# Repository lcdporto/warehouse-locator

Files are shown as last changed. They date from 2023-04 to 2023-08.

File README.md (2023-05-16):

# Warehouse Locator - An LED based stock search helper
Identifying a specific stock items inside a dense environment, such as a warehouse, is difficult so we developed a LED strip based system that lights up around the stock item requested.

This system is connected via WiFi to a MQTT broker and is able to receive commands to light up any given set of LEDs.

## Set up the server
The server is simply a MQTT broker. To setup the server you need to install [Docker](https://docs.docker.com/get-docker/) and [Docker Compose](https://docs.docker.com/compose/install/).

1. Because this will be a publicly accessible MQT broker,before you run the server, you need to define its access credentials. For that create a file on ```server/mosquitto/mosquitto.passwd``` with your user and password separated by a colon, here is an example:
```
lcdporto:very-strong-password
```
2. Then you are ready to start the server:

```
docker-compose up -d
```
3. Before you can use it you need to encrypt the password file:
```
docker exec -it mosquitto mosquitto_passwd -U /mosquitto/config/mosquitto.passwd
```
4. Then restart your server with:
```
docker-compose restart mosquitto
```
Now your server is up and running!

## Prepare your device

The hardware is composed of a ESP32 and LED strips. The hardware connections are simple:
| ESP32  | LED strip |
| --- | --- |
| GPIO15 | DATA |
| GPIO16 | DATA |
| GPIO19 | DATA |
| GPIO22 | DATA |
| GPIO21 | DATA |
| GPIO25 | DATA |

You can change this pin assignment as well as add more LED strips on the firmware. Your limitation is the RAM usage and the pin count of your board.

1. First you need to setup your computer to build the firmware with one of the two methods:
   - At the time of this writing the recommended method is to use [VS Code](https://code.visualstudio.com/) and the [official PlatformIO extension](https://marketplace.visualstudio.com/items?itemName=platformio.platformio-ide) which is a procedure that works on Windows, macOS and Linux foloowing the [the official documentation.](https://platformio.org/platformio-ide).\
   - You can also use a CLI approach that is available on all major platforms as well which have Python installed (follow [this guide](https://wiki.python.org/moin/BeginnersGuide/Download)) and then on the ```firmware``` folder run the following lines on the terminal of your operative system:
    ```
    pip install --user platformio
    pio run --target upload
    ```
    **Note:** you may need to reboot your system between the two commands for the *pio* executable to be available.

2. Next, you need to configure your device's WiFi network and MQTT broker details. To do that, power up your device and search for a WiFi network named after this project "warehouse-locator-\<ID\>" (note down the ID, or check later with this). Connect to it and you should be promted to login to the network on a captive portal. There is where you find a form to fill in your WiFi credentials and MQTT server details. If your device fails to connect to the network the configuration WiFi network will show up again after a few seconds.\
Alternatively, you can upload a file containing the MQTT server details (```firmware/data/config.json```) to the ESP32 filesystem following the [this guide](https://randomnerdtutorials.com/esp32-vs-code-platformio-spiffs/). Keep in mind that you still need to follow the captive portal procedure to enter your WiFi credentials.

Now your device is connected to the internet and able to receive messages from your broker that change the state of the LED strips you have hooked up.

## Discover connected devices

To discover connected devices and check their ID, the topic ```warehouse-locator/+``` can be subscribed and devices will periodically publish on that topic to announce themselves and you can check their ID on the topic name they use. Notice that the subscription topic suggested has the "+" wildcard, this means you'll subscribe to all devices announce topic.

An example on how you can listen to these messages is [here](.examples/../examples/discover_devices.py).

## Send commands

The device can be controlled by sending a MQTT message to the broker identifying the device, led-strip and led index and two modes are supported:

### Single LED control
**Topic:** `warehouse-locator/<deviceId>/<strip-id>/<led-id>`\
**Payload:**
```json
{
  "color": {
    "r": 0,
    "g": 255,
    "b": 0
  },
  "timeout": 5
}
```

### Multiple LED control
**Topic:** `warehouse-locator/<deviceId>/multiple`\
**Payload:**
```json
{
  "strip": 3,
  "from": 1,
  "to": 4,
  "color": {
    "r": 255,
    "g": 255,
    "b": 255
  },
  "timeout": 5
}
```
**Note:** For maintenance purposes the LEDs can be blinked sequentially if the payload is not a JSON object and just set to ```all```

Examples for both modes can be found at the [examples](./examples) folder.

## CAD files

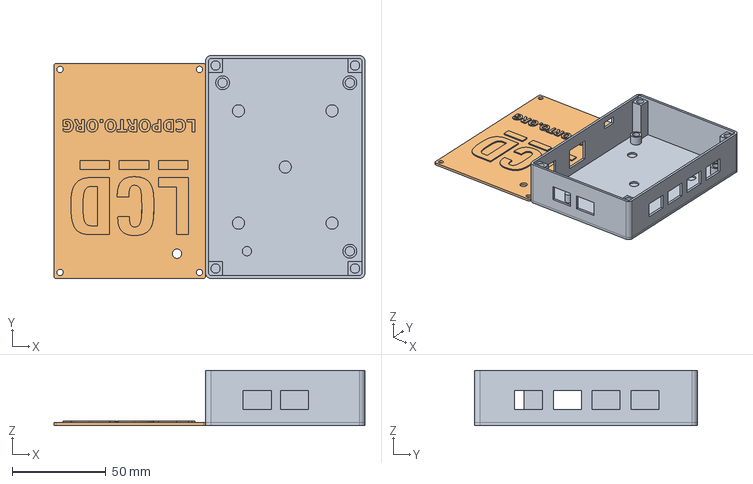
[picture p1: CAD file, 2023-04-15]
cad/warehouse-locator.FCStd
166.2 x 119.2 x 29.6 mm
case
lid

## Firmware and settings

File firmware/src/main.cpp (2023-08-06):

#include <ArduinoJson.h>
#include <EthernetENC.h>
#include <FastLED.h>
#define MQTT_MAX_PACKET_SIZE 2048
#include <PubSubClient.h>
#include <SPIFFS.h>
#include <WiFi.h>

#define LED_STRIP_1_PIN 2
#define LED_STRIP_2_PIN 4
#define LED_STRIP_3_PIN 16
#define LED_STRIP_4_PIN 17
#define LED_STRIP_5_PIN 21
#define LED_STRIP_6_PIN 22

#define NUM_LEDS 144 * 5
#define NUM_STRIPS 6

#define CONFIG_FILE_PATH "/config.json"
#define ID_FILE_PATH "/device-id.txt"

#define MQTT_TOPIC_PREFIX "warehouse-locator/"

#define MQTT_ANNOUNCE_PERIOD 30 // in seconds

#define LED_OFF_PAYLOAD "{\"color\":{\"r\": 0,\"g\": 0,\"b\":0}}"

#define MQTT_SERVER "test.mosquitto.org"
#define MQTT_PORT 1883
#define MQTT_USER "mqtt_user"
#define MQTT_PASS "mqtt_password"

char device_id[11] = "";

static CRGB led_strips[NUM_STRIPS][NUM_LEDS];

EthernetClient ethernet_client;
PubSubClient mqtt(ethernet_client);

static bool test_running = false;

char connection_state[64] = "";

typedef struct {
  uint8_t strip;
  uint16_t led[128];
  uint8_t n_leds;
  uint8_t r = 255;
  uint8_t g = 255;
  uint8_t b = 255;
  uint16_t timeout = 5;
} led_ctrl;

void control_LEDs(void *led_arg) {
  led_ctrl led;
  memcpy(&led, led_arg, sizeof(led_ctrl));

  for (uint8_t i = 0; i < led.n_leds; i++) {
    led_strips[led.strip][led.led[i]] = CRGB(led.r, led.g, led.b);
  }
  FastLED.show();

  vTaskDelay((led.timeout * 1000) / portTICK_PERIOD_MS);

  for (uint8_t i = 0; i < led.n_leds; i++) {
    led_strips[led.strip][led.led[i]] = CRGB(0, 0, 0);
  }
  FastLED.show();

  vTaskDelete(NULL);
}

/**
 * @brief Turns the LEDs of all LED strips sequentially in a fading sequence
 *
 * @param group_size number of LEDs to be lit at each time
 */
void LED_init_sequence(uint16_t group_size = 3) {
  test_running = true;
  for (uint16_t j = 0; j < NUM_LEDS; j++) {
    for (uint8_t i = 0; i < NUM_STRIPS; i++) {
      led_strips[i][j] = CRGB(255, 255, 255);
    }
    if (j - group_size >= 0) {
      for (uint8_t i = 0; i < NUM_STRIPS; i++) {
        led_strips[i][j - group_size] = CRGB(0, 0, 0);
      }
    }
    FastLED.show();
    log_d("Lighting up LED # %d", j);
  }
  test_running = false;
}

void mqtt_receive(char *topic, byte *payload, unsigned int length) {
  log_d("Message arrived [%s]: %s", topic, strndup((char *)payload, length));

  // skip prefix, device ID and forward slash
  topic += strlen(MQTT_TOPIC_PREFIX) + 10 + 1;

  log_d("Trimmed topic to %s", topic);

  char *token = strtok(topic, "/");
  if (strcmp(token, "multiple") == 0) {

    DynamicJsonDocument doc(2048);
    if (deserializeJson(doc, (char *)payload)) {
      log_e("Received invalid JSON");
      return;
    }
    log_d("Deserialized JSON successfully");
    log_d("Doc has size: %d", doc.size());

    uint16_t timeout;
    if (doc.containsKey("timeout")) {
      timeout = doc["timeout"];
    } else {
      timeout = 5;
    }

    log_d("Received command to control %d LEDs", doc["leds"].size());

    led_ctrl led_c;
    led_c.strip = doc["strip"];
    uint16_t from_led = doc["from"].as<uint16_t>();
    uint16_t to_led = doc["to"].as<uint16_t>();
    uint16_t nleds = to_led - from_led + 1;
    nleds = nleds > 128 ? 128 : nleds;
    for (uint8_t i = 0; i < nleds; i++) {
      led_c.led[i] = from_led + i;
    }
    led_c.n_leds = nleds;
    led_c.r = doc["color"]["r"];
    led_c.g = doc["color"]["g"];
    led_c.b = doc["color"]["b"];
    led_c.timeout = timeout;

    xTaskCreate(control_LEDs, "control_LEDs", 4096, &led_c, 1, NULL);
  } else if (strcmp(token, "test") == 0) {
    LED_init_sequence();
  } else {
    uint8_t strip_n;
    uint16_t led_n;

    strip_n = atoi(token);
    led_n = atoi(strtok(NULL, "/"));

    log_d("Addressed strip %u and led %u", strip_n, led_n);

    DynamicJsonDocument doc(128);
    if (deserializeJson(doc, (char *)payload)) {
      log_e("Received invalid JSON");
      return;
    }
    log_d("Deserialized JSON successfully");
    log_d("Doc has size: %d", doc.size());

    uint16_t timeout;
    if (doc.containsKey("timeout")) {
      timeout = doc["timeout"];
    } else {
      timeout = 5;
    }

    led_ctrl led_c;
    led_c.strip = strip_n;
    led_c.led[0] = led_n;
    led_c.n_leds = 1;
    led_c.r = doc["color"]["r"];
    led_c.g = doc["color"]["g"];
    led_c.b = doc["color"]["b"];
    led_c.timeout = timeout;

    xTaskCreate(control_LEDs, "control_LEDs", 4096, &led_c, 1, NULL);
  }
}

bool mqtt_connect() {
  if (mqtt.connected())
    return true;

  bool status = mqtt.connect(device_id, MQTT_USER, MQTT_PASS);

  if (status == false) {
    return false;
  }
  char topic[64];
  sprintf(topic, "%s%s/+/+", MQTT_TOPIC_PREFIX, device_id);
  mqtt.subscribe(topic, 1);
  log_v("Subscribed to topic: %s", topic);

  sprintf(topic, "%s%s/test", MQTT_TOPIC_PREFIX, device_id);
  mqtt.subscribe(topic);
  log_v("Subscribed to topic: %s", topic);

  sprintf(topic, "%s%s/multiple", MQTT_TOPIC_PREFIX, device_id);
  mqtt.subscribe(topic, 1);
  log_v("Subscribed to topic: %s", topic);

  log_i("Connected to MQTT server: %s:%d", MQTT_SERVER, MQTT_PORT);

  return mqtt.connected();
}

void mqtt_announce(void *) {
  while (1) {
    if (mqtt_connect()) {
      char topic[64];
      sprintf(topic, "%s%s", MQTT_TOPIC_PREFIX, device_id);
      mqtt.publish(topic, connection_state);
    }
    vTaskDelay(MQTT_ANNOUNCE_PERIOD * 1000 / portTICK_PERIOD_MS);
  }
}

void setup() {
  FastLED.addLeds<WS2812, LED_STRIP_1_PIN, GRB>(led_strips[0], NUM_LEDS);
  FastLED.addLeds<WS2812, LED_STRIP_2_PIN, GRB>(led_strips[1], NUM_LEDS);
  FastLED.addLeds<WS2812, LED_STRIP_3_PIN, GRB>(led_strips[2], NUM_LEDS);
  FastLED.addLeds<WS2812, LED_STRIP_4_PIN, GRB>(led_strips[3], NUM_LEDS);
  FastLED.addLeds<WS2812, LED_STRIP_5_PIN, GRB>(led_strips[4], NUM_LEDS);
  FastLED.addLeds<WS2812, LED_STRIP_6_PIN, GRB>(led_strips[5], NUM_LEDS);

  for (uint8_t i = 0; i < NUM_STRIPS; i++) {
    for (uint16_t j = 0; j < NUM_LEDS; j++) {
      led_strips[i][j] = CRGB(0, 0, 0);
    }
  }
  for (uint8_t i = 0; i < NUM_STRIPS; i++) {
    led_strips[i][0] = CRGB(64, 0, 0);
  }
  FastLED.show();

  SPIFFS.begin(true);
  if (SPIFFS.exists(ID_FILE_PATH)) {
    fs::File device_id_file = SPIFFS.open(ID_FILE_PATH, "r");
    device_id_file.readBytes(device_id, 11);
    device_id_file.close();
  } else {
    fs::File device_id_file = SPIFFS.open(ID_FILE_PATH, "w");
    sprintf(device_id, "%010u", esp_random());
    device_id_file.print(device_id);
    device_id_file.close();
  }

  log_i("Device ID: %s", device_id);

  Ethernet.init(5);
  uint8_t mac[6];
  WiFi.macAddress(mac);
  Ethernet.begin(mac);

  if (Ethernet.linkStatus() == LinkON) {
    sprintf(connection_state, "Ethernet: %s",
            Ethernet.localIP().toString().c_str());
  } else {
    delay(5000);
    ESP.restart();
  }
  log_i("%s", connection_state);
  if (strcmp(Ethernet.localIP().toString().c_str(), "0.0.0.0") == 0) {
    delay(5000);
    ESP.restart();
  }
  log_i("%s", connection_state);

  for (uint16_t i = 0; i < NUM_STRIPS; i++) {
    led_strips[i][0] = CRGB(0, 64, 0);
  }
  FastLED.show();
  delay(5000);
  for (uint16_t i = 0; i < NUM_STRIPS; i++) {
    led_strips[i][0] = CRGB(0, 0, 0);
  }
  FastLED.show();

  log_i("Connecting with mac address: %s", WiFi.macAddress().c_str());

  log_d("Configuring MQTT server");
  mqtt.setServer(MQTT_SERVER, MQTT_PORT);

  log_d("Configuring MQTT callback");
  mqtt.setCallback(mqtt_receive);

  log_d("Setting up keep alive MQTT message");
  xTaskCreate(mqtt_announce, "announce_ID", 2048, NULL, 1, NULL);
}

void loop() {
  if (mqtt_connect()) {
    mqtt.loop();
  }
}

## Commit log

2022-05-24 Prototype firmware
2022-05-24 Add support for multiple LED strips
2022-06-19 fix device ID and change board to lolin32
    [main.cpp]
2022-07-11 Fix WiFi Credentials save
    [main.cpp]
2022-07-11 filter messages on dev id
2022-07-29 Docs: device configuration details
2022-08-27 group LED control
2022-08-27 timeout and device discovery, fixes #3 and #4
    [main.cpp]
2022-08-27 device discovery docs
2022-08-27 missing turn off led
    [main.cpp]
2022-09-02 Publish LED state
2022-09-02 MQTT retain flag and fixed MQTT topic
    [main.cpp]
2022-10-04 Added 3D printed case CAD
    [warehouse-locator.FCStd]
2022-10-05 USB hole for the case
    [warehouse-locator.FCStd]
2022-10-05 Case magnet mounts
    [warehouse-locator.FCStd]
2022-10-05 Case lid
    [warehouse-locator.FCStd]
2022-10-06 Add website to lid
    [warehouse-locator.FCStd]
2022-10-07 Fix dimensions and link font
    [warehouse-locator.FCStd]
2022-10-07 lid logo extruded
    [warehouse-locator.FCStd]
2022-10-09 Change link to embossed
    [warehouse-locator.FCStd]
2022-11-26 helper PCB
    [warehouse-locator.kicad_pcb, warehouse-locator.kicad_sch]
2022-11-26 Ethernet header
    [warehouse-locator.kicad_pcb, warehouse-locator.kicad_sch]
2022-11-26 blink all LEDs sequentially
2022-11-26 added python example to blink all LEDs
2023-01-04 Component positioning
    [warehouse-locator.kicad_pcb, warehouse-locator.kicad_sch]
2023-01-04 Pins connected
    [warehouse-locator.kicad_pcb, warehouse-locator.kicad_sch]
2023-01-04 Board routed
    [warehouse-locator.kicad_pcb]
2023-01-04 Ignore gerber folder
2023-01-04 Add Status LED
    [warehouse-locator.kicad_pcb, warehouse-locator.kicad_sch]
2023-01-04 Commit missing file
    [warehouse-locator.kicad_sch]
2023-02-28 Handle startup without Ethernet cable connected
2023-03-06 Change CAD to new dimensions, access holes missing
    [warehouse-locator.FCStd]
2023-03-08 Fix pin assignments
2023-03-08 CAD access holes
    [warehouse-locator.FCStd]
2023-03-10 LED access holes
    [warehouse-locator.FCStd]
2023-03-10 Fix font and some dimensions
    [warehouse-locator.FCStd]
2023-04-15 LED init sequence and Ethernet
2023-05-06 hot swap between ethernet and WiFi
    [main.cpp]
2023-05-06 chande LED test topic name
2023-05-06 decrease brightness of link status LED
2023-05-06 reconnect to WiFi if fails
    [main.cpp]
2023-05-13 Addd LED state and simplify code
2023-08-06 Remove LED limiting
2023-08-06 Fix LED boundary
